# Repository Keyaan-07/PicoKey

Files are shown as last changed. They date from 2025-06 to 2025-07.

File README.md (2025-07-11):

# PicoKey 

I go to highschool, and teens are always around when i try to login to my mail or github or any other account, so my password can be compromised.  

To solve this, I created PicoKey, which is a hardware pass key in a very small form factor(34.5mm x 18.5mm). It uses the RP2350A chip, although I wanted to use my favourite MCU, the rp2040, it was not safe as a pass key, so I used the rp2350A this time, which is much more safer and secure than the RP2350A.  

I think it can also function as a USB-HID device because it has an external button too and 16Mb of memory size.

It has USB-A in the PCB itself soo need for external connectors, however, you either need to order a 2.0mm thick PCB(expensive) or you need to order a 1.6mm PCB(pretty cheap) and make up for the 0.4mm using tape or some other method.  

### Features:
> Small form factor: 3.45cm x 1.85 cm  
> Uses the latest MCU from Raspberyy Pi, the RP2350A  
> Could Potentially have HID Compatibility  
> USB inbuilt the PCB

Idea taken from ```@Rudy``` 's [RP2350 hardware key](https://github.com/Outdatedcandy92/PicoDucky)  

# How to Assemble this PCB?

It is basically a single pcb, so assembling this project means soldering on all the components.  

To solder, I would recommend buying a stencil along with the PCBs, or opting for PCBA from your PCB manufacturer, I am using [JLC](https://jlcpcb.com) for this, and I will be opting for PCBA, as this is a 2 sided board, it will be much easier for 1 side to be PCBA(bottom side) and other by hand(top side).  

The RP2350A is housed on the bottom side along with most of the components, and I have placed easy to solder components on the top, and the small pads for resistors and LED are a little bigger, which would help in soldering by hand.

# Why i chose to make this project
I chose to make this project mainly for 2 reasons:  

1. i wanted to have a secure hardware key and didn't wanna sign in using passwords in front of everyone.  

2. I wanted to try out making a 2 sided PCB(where components are on 2 sides), to learn how to make such projects and the learning curve for dual sided PCBs.  

# Images
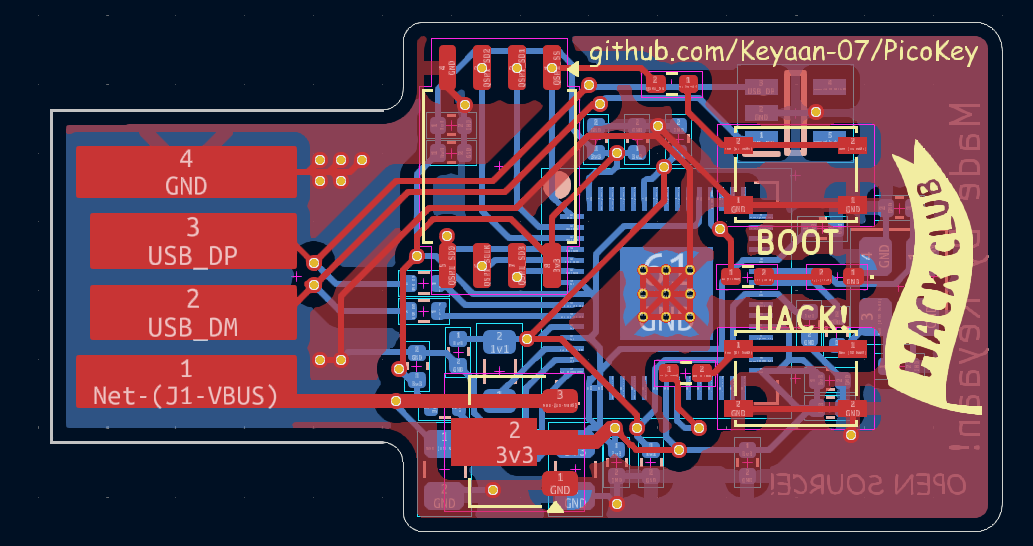
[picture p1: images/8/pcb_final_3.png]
final pcb img
  
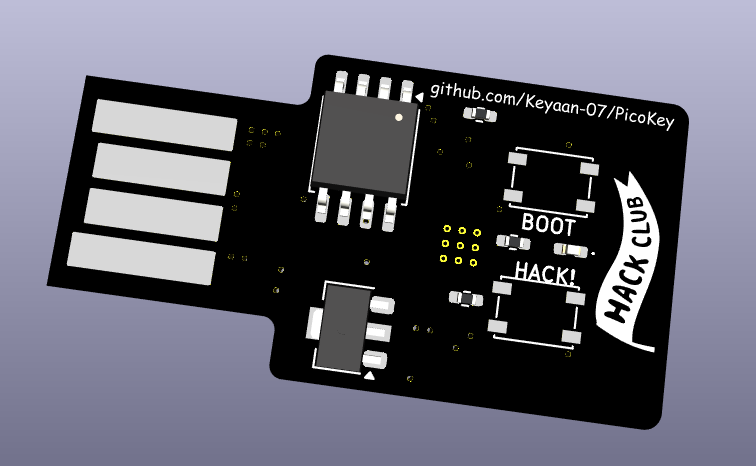
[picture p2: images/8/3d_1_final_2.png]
final cad 1
  
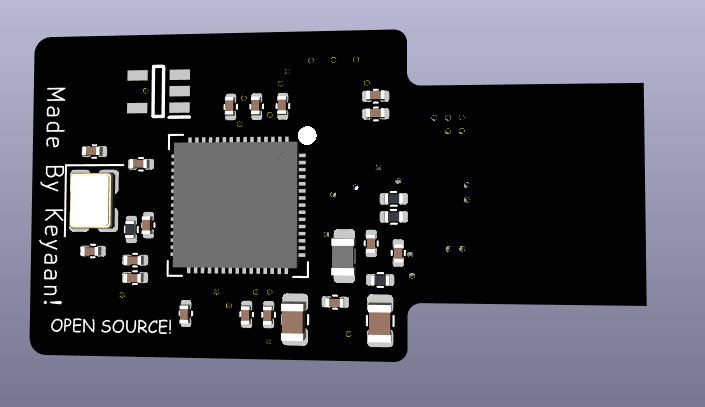
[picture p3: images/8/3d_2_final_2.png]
final cad 2
  
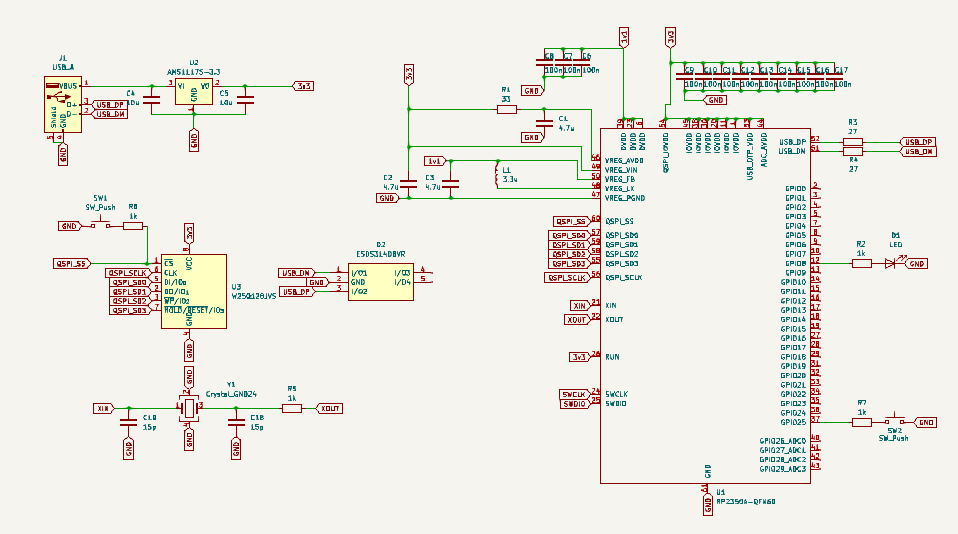
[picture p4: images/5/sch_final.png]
final sch img
  

# BOM

| ITEM NAME | ITEM PRICE | FUNCTION | URL |
| --- | --- | --- | --- |
| Pcb Manufacturing + stencil | 23.82 | main pcb and smt stencil | [https://jlcpcb.com](https://jlcpcb.com/) |
| PCB Components | 21.1131 | components on the PCB | [https://lcsc.com](https://lcsc.com/) |
|  Total | 44.93 | USD | |

# PCB Components Breakdown

### Note: There are a few resistors and capacitors, which had very high minimum order quantity(MOQ), about 50 pieces so i had to forcefully include those, which i will be utilising in my next highway projects. And tbh the prices were very less(about $0.02 per piece) so i think it is alright

### if DNO is yes, i am not ordering the respective parts and thus i have not included the cost in BOM.

| Id | Designator | Designation | MPN | Footprint | DNO - Do not order | MOQ | Price  | Quantity | Amount | Supplier link |
| -- | --- | --- | --- | --- | --- | --- | --- | --- | --- | --- |
| 1  | C1, C2, C3 | 4.7u | GRM155R61C475KE15D | 402 | No | Yes | 0.057  | 10 | 0.57 | https://lcsc.com/product-detail/Multilayer-Ceramic-Capacitors-MLCC-SMD-SMT_Murata-Electronics-GRM155R61C475KE15D_C426094.html |
| 2  | C10, C11, C12, C13, C14, C15, C16, C17, C6, C7, C8, C9 | 100n | GRM155R61H104JE14D | 402 | Yes | \-  | 0 | 36 | 0 | https://lcsc.com/product-detail/Multilayer-Ceramic-Capacitors-MLCC-SMD-SMT_Murata-Electronics-GRM155R61H104JE14D_C426067.html |
| 3  | C18, C19 | 15p | GJM1555C1H150FB01D | 402 | Yes | \-  | 0 | 6 | 0 | https://lcsc.com/product-detail/Multilayer-Ceramic-Capacitors-MLCC-SMD-SMT_Murata-Electronics-GJM1555C1H150FB01D_C441742.html |
| 4  | C4, C5 | 10u | CL21A106KBVNNNE | 805 | No | Yes | 0.046  | 5 | 0.23 | https://lcsc.com/product-detail/Multilayer-Ceramic-Capacitors-MLCC-SMD-SMT_Samsung-Electro-Mechanics-CL21A106KBYQNNE_C2932476.html |
| 5  | D1 | LED | 19-213-GHC-YR1S1N-3T  | 402 | Yes | \-  | 0 | 3 | 0 | https://www.lcsc.com/product-detail/LED-Indication-Discrete_Everlight-Elec-16-213-GHC-YR1S1N-3T_C2980183.html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 |
| 6  | D2 | ESDS314DBVR | ESD5314DBVR | 402 | No | Yes | 0.212  | 5 | 1.06 | https://lcsc.com/product-detail/ESD-and-Surge-Protection-TVS-ESD_TI-ESDS314DBVR_C1847859.html |
| 7  | J1 | USB_A | \- | USBPCB | On PCB | \-  | \- | \- | \- | \- |
| 8  | L1 | 3.3u | A201610S3R3-101-T | 806 | No | Yes | 0.2592 | 5 | 1.3 | https://lcsc.com/product-detail/Power-Inductors_Abracon-LLC-AOTA-B201610S3R3-101-T_C42411119.html |
| 9  | R1 | 33 | RT0402BRD0733RL | 402 | No | Yes | 0.0198 | 50 | 0.99 | https://lcsc.com/product-detail/Chip-Resistor-Surface-Mount_YAGEO-RT0402BRD0733RL_C852729.html |
| 10 | R2, R5, R6, R7 | 1k | CRCW040210K0FKEDHP | 402 | No | Yes | 0.023  | 20 | 0.46 | https://lcsc.com/product-detail/Chip-Resistor-Surface-Mount_Vishay-Intertech-CRCW04021K00FKEDHP_C313354.html |
| 11 | R3, R4 | 27 | ERJ2GEJ270X | 402 | Yes | \-  | 0 | 6 | 0 | https://lcsc.com/product-detail/Chip-Resistor-Surface-Mount_PANASONIC-ERJ2GEJ270X_C278580.html |
| 12 | SW1, SW2 | SW_Push | K-PTS810SJMS205MTLFSG | SW_SPST_PTS810 | No | No  | 0.6 | 6 | 3.6 | https://lcsc.com/product-detail/Tactile-Switches_C-K-PTS810SJM250SMTRLFS_C116501.html |
| 13 | U1 | RP2350A-QFN60 | RPi2350 | QFN-60 | No | No  | 1.514  | 3 | 4.542  | https://www.silverlineelectronics.in/collections/the-raspberry-pi/products/rp2350a-raspberry-pi-microcontroller-chip-in-stock-silverline-india |
| 14 | U2 | AMS1117S-3.3  | AMS1117-3.3 | SOT-89-3 | No | Yes | 0.1 | 5 | 0.5 | https://lcsc.com/product-detail/Voltage-Regulators-Linear-Low-Drop-Out-LDO-Regulators_JSMSEMI-AMS1117S-3-3_C917152.html |
| 15 | U3 | W25Q128JVS | W25Q128JVSIM | SOIC-8_5.3x5.3mm_P1.27mm | Yes | \-  | 0 | 3 | 0 | https://lcsc.com/product-detail/NOR-FLASH_Winbond-Elec-W25Q128JVSIM_C2613930.html |
| 16 | Y1 | Crystal_GND24 | ABM8-27-T3 | Crystal_SMD_3225-4Pin_3.2x2.5mm | No | No  | 0.3737 | 3 | 1.1211 | https://www.lcsc.com/product-detail/Crystals_Abracon-LLC-ABM8-272-T3_C20625731.html?s_z=n_abm8 |
| | | Shipping | 3.74 | | | | | | | |
| | | Handling fee  | 3 | | | | | | | |
| | | Total | 21.1131 | USD | | | | | | |

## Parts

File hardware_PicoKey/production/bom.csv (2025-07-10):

Designator | Footprint | Quantity | Value | LCSC Part #
C1, C2, C3 | 402 | 3 | 4.7u
C10, C11, C12, C13, C14, C15, C16, C17, C6, C7, C8, C9 | 402 | 12 | 100n
C18, C19 | 402 | 2 | 15p
C4, C5 | 805 | 2 | 10u
D1 | 402 | 1 | LED
D2 | ESDS314BVR_SOT95P280X145-5N | 1 | ESDS314DBVR
J1 | USBPCB | 1 | USB_A
L1 | 805 | 1 | 3.3u
R1 | 402 | 1 | 33
R2, R5, R6, R7 | 402 | 4 | 1k
R3, R4 | 402 | 2 | 27
SW1, SW2 | SW_SPST_PTS810 | 2 | SW_Push
U1 | RP2350A_QFN-60_EP_7.75x7.75_Pitch0.4mm | 1 | RP2350A-QFN60
U2 | SOT-89-3 | 1 | AMS1117S-3.3
U3 | SOIC-8_5.3x5.3mm_P1.27mm | 1 | W25Q128JVS
Y1 | Crystal_SMD_3225-4Pin_3.2x2.5mm | 1 | Crystal_GND24

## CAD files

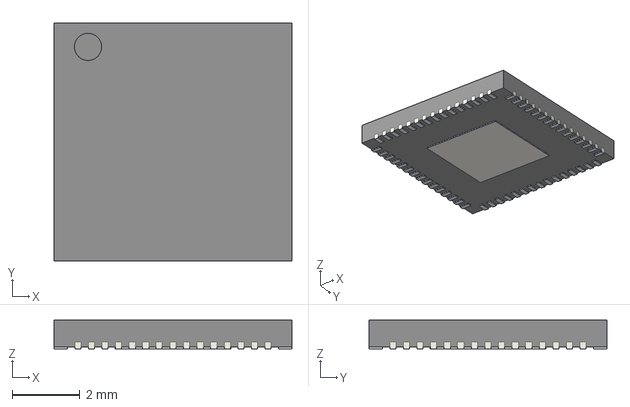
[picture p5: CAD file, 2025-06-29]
hardware_PicoKey/footprints/RP2350A-QFN60.step
7.00 x 7.00 x 0.85 mm

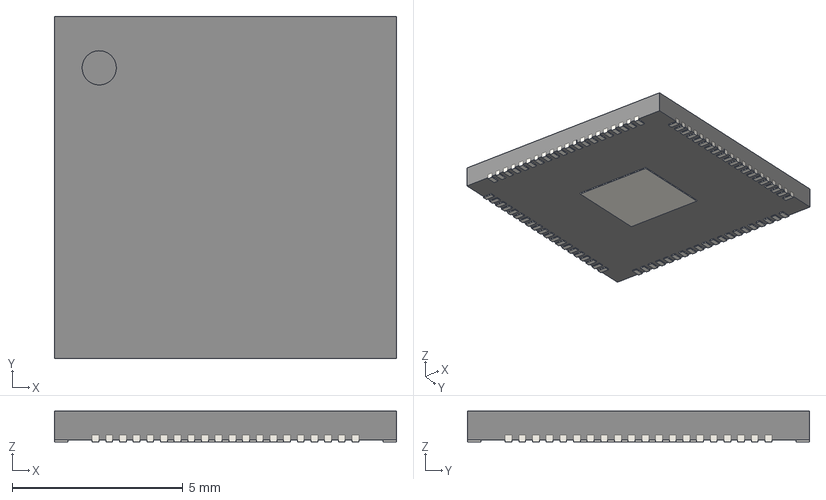
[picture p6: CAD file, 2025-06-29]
hardware_PicoKey/footprints/RP2350B-QFN80.step
10.0 x 10.0 x 0.9 mm

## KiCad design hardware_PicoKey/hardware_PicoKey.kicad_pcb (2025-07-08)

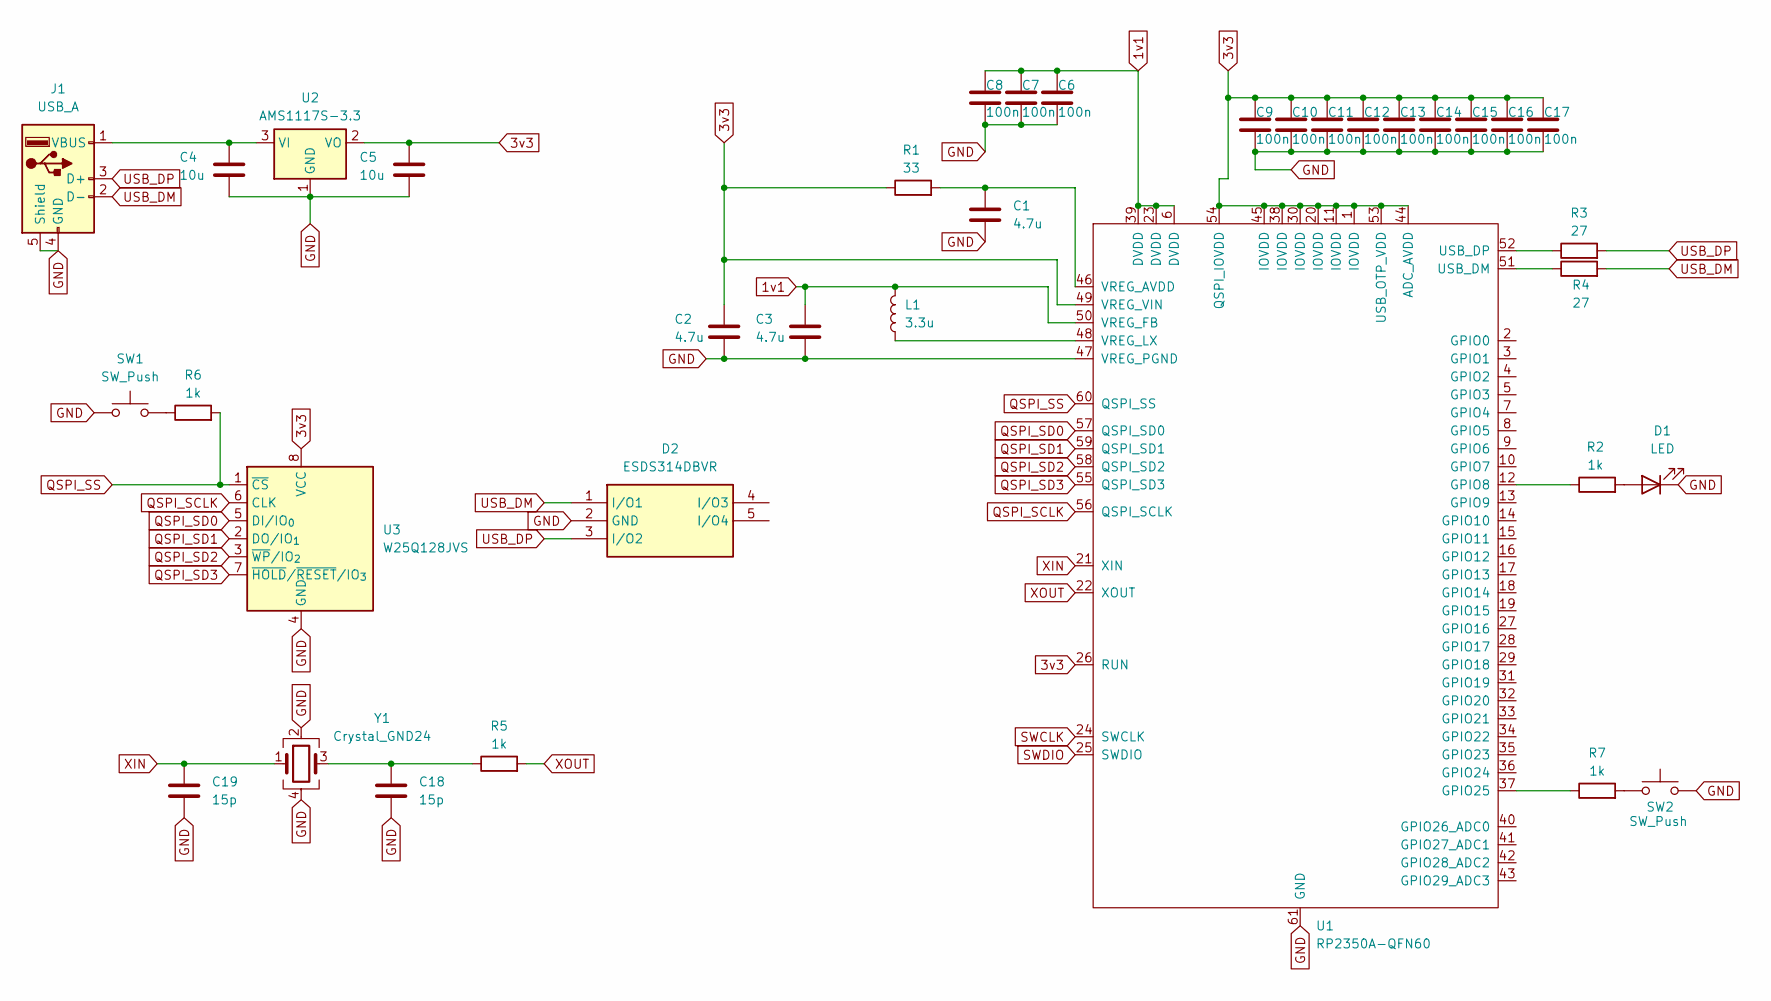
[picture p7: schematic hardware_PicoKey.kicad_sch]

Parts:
C1, C2, C3: 4.7u; C_0402_1005Metric
C4, C5: 10u; C_0805_2012Metric
C6, C7, C8, C9, C10, C11, C12, C13, C14, C15, C16, C17: 100n; C_0402_1005Metric
C18, C19: 15p; C_0402_1005Metric
D1: LED; LED_0402_1005Metric_Pad0.77x0.64mm_HandSolder
D2: ESDS314DBVR; ESDS314BVR_SOT95P280X145-5N; Mouser Part Number 595-ESDS314DBVR
J1: USB_A; USBPCB
L1: 3.3u; L_0805_2012Metric
R1: 33; R_0402_1005Metric
R2, R6, R7: 1k; R_0402_1005Metric_Pad0.72x0.64mm_HandSolder
R3, R4: 27; R_0402_1005Metric
R5: 1k; R_0402_1005Metric
SW1, SW2: SW_Push; SW_SPST_PTS810
U1: RP2350A-QFN60; RP2350A_QFN-60_EP_7.75x7.75_Pitch0.4mm
U2: AMS1117S-3.3; SOT-89-3
U3: W25Q128JVS; SOIC-8_5.3x5.3mm_P1.27mm
Y1: Crystal_GND24; Crystal_SMD_3225-4Pin_3.2x2.5mm

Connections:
1v1: C3.1, C6.1, C7.1, C8.1, L1.2, U1.6 (DVDD), U1.23 (DVDD), U1.39 (DVDD), U1.50 (VREG_FB)
3v3: C2.1, C5.1, C9.1, C10.1, C11.1, C12.1, C13.1, C14.1, C15.1, C16.1, C17.1, R1.1, U1.1 (IOVDD), U1.11 (IOVDD), U1.20 (IOVDD), U1.26 (RUN), U1.30 (IOVDD), U1.38 (IOVDD), U1.44 (ADC_AVDD), U1.45 (IOVDD), U1.49 (VREG_VIN), U1.53 (USB_OTP_VDD), U1.54 (QSPI_IOVDD), U2.2 (VO), U3.8 (VCC)
GND: C1.2, C2.2, C3.2, C4.2, C5.2, C6.2, C7.2, C8.2, C9.2, C10.2, C11.2, C12.2, C13.2, C14.2, C15.2, C16.2, C17.2, C18.2, C19.2, D1.1 (K), D2.2 (GND), J1.4 (GND), J1.5 (Shield), SW1.1, SW2.2, U1.47 (VREG_PGND), U1.61 (GND), U2.1 (GND), U3.4 (GND), Y1.2, Y1.4
unnamed: C18.1, R5.1, Y1.3
unnamed: D1.2 (A), R2.2
unnamed: C4.1, J1.1 (VBUS), U2.3 (VI)
unnamed: R6.1, SW1.2
unnamed: R7.2, SW2.1
unnamed: R2.1, U1.12 (GPIO8)
unnamed: R7.1, U1.37 (GPIO25)
unnamed: R4.1, U1.51 (USB_DM)
unnamed: R3.1, U1.52 (USB_DP)
unnamed: C1.1, R1.2, U1.46 (VREG_AVDD)
unnamed: L1.1, U1.48 (VREG_LX)
QSPI_SCLK: U1.56 (QSPI_SCLK), U3.6 (CLK)
QSPI_SD0: U1.57 (QSPI_SD0), U3.5 (DI/IO_{0})
QSPI_SD1: U1.59 (QSPI_SD1), U3.2 (DO/IO_{1})
QSPI_SD2: U1.58 (QSPI_SD2), U3.3 (~WP/IO_{2})
QSPI_SD3: U1.55 (QSPI_SD3), U3.7 (~HOLD/~RESET/IO_{3})
QSPI_SS: R6.2, U1.60 (QSPI_SS), U3.1 (~CS)
SWCLK: U1.24 (SWCLK)
SWDIO: U1.25 (SWDIO)
USB_DM: D2.1 (I/O1), J1.2 (D-), R4.2
USB_DP: D2.3 (I/O2), J1.3 (D+), R3.2
XIN: C19.1, U1.21 (XIN), Y1.1
XOUT: R5.2, U1.22 (XOUT)

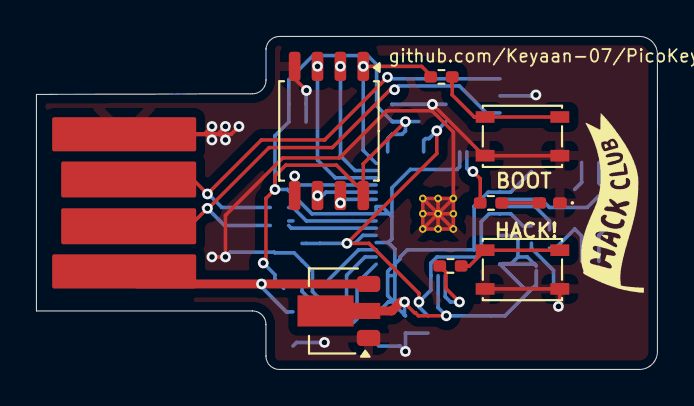
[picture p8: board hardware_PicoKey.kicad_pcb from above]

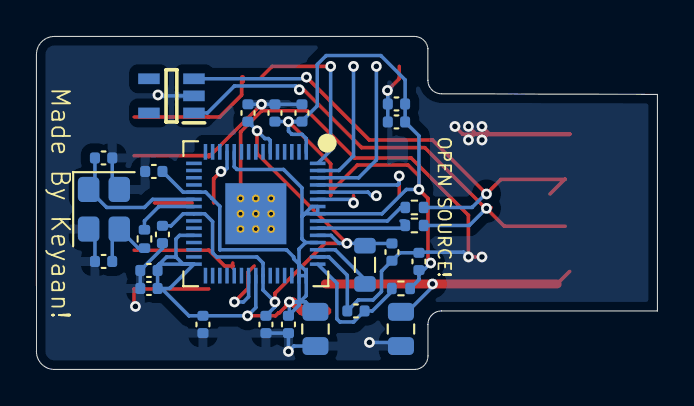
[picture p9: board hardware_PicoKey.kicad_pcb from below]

Board: 2 copper layers, 34.5 x 18.5 mm, 36 parts (27 on the bottom side), 24 nets.

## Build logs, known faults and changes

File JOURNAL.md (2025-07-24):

---
title: "PicoKey"
author: "Keyaan"
description: "A Pass Key(Like Yubikey) using the RP2350A from Raspberyy Pi!"
created_at: "2025-06-26"
---
# Total time spent: about 6 hours
# this work is not at all copied from rudy, i wanted to create my own thats all

----
# June 26 2025
Yup, I wanna make a hardware key. I was inspired by yubikey, [orpheus pico guide](http://orpheuspico.hackclub.com/docs/pico/guides/passkey), and the [RP2350 hardware key](https://github.com/Outdatedcandy92/PicoDucky) by ```@Rudy```

I might start from tomorrow.  

----
# June 27 2025

Beginning my work on PicoKey from today. The things i will try to accomplish:
> PCB Trace USB Connector  
> Use an RP2350 instead of RP2040 this time:(  
> smallest possible footprint  
> also add HID compatability
  
I wanted to use the RP2040 but it is apparently not secure enough so now i have to use the RP2350 :(

Gotta start with the schematic(i didn't)

----
# June 29 2025

Finally, my test is over today and now i can work on this PCB. so, starting with the schematic from now on.

### Time spent: about 1 hour (had to learn the rp2350 design guide)

----
# June 30 2025
I did the work yesterday but then i was ordered to chut down the laptop immediately, so i had to go, anyways, here are the pictures from yesterday:

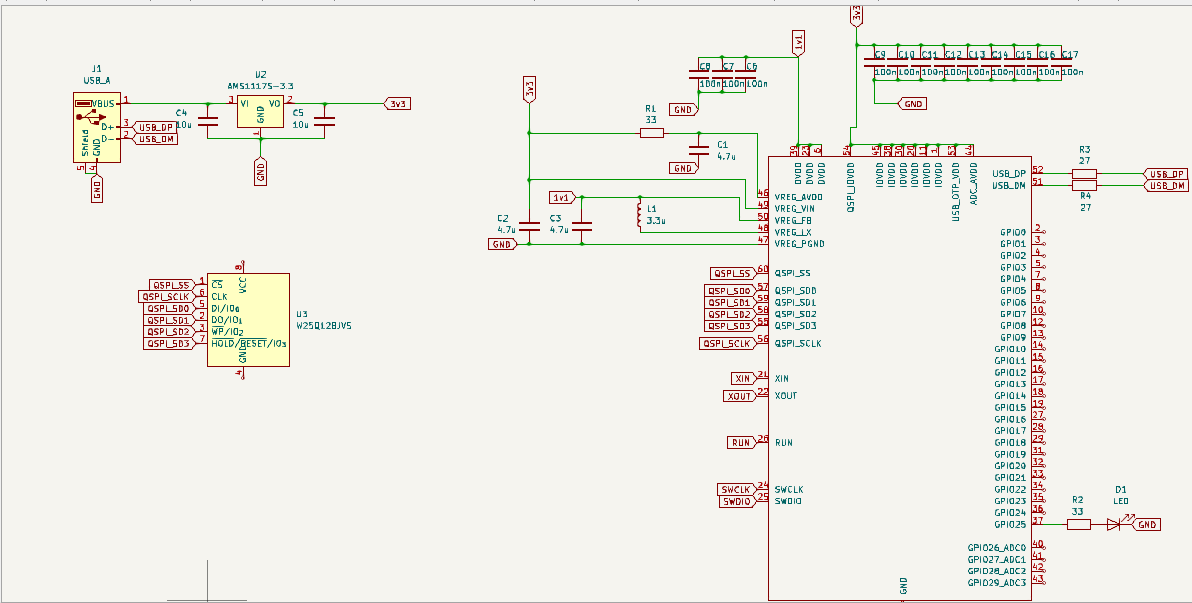
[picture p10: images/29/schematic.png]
schematic


i didn't work on anything else.

----
# July 1 2025

I have thought of something, maybe, i can also make the device as an HID, like how ```@Rudy``` made it, so i am gonna do that probably and complete the pcb today itself.  
I think the schematic is complete, here it is:  
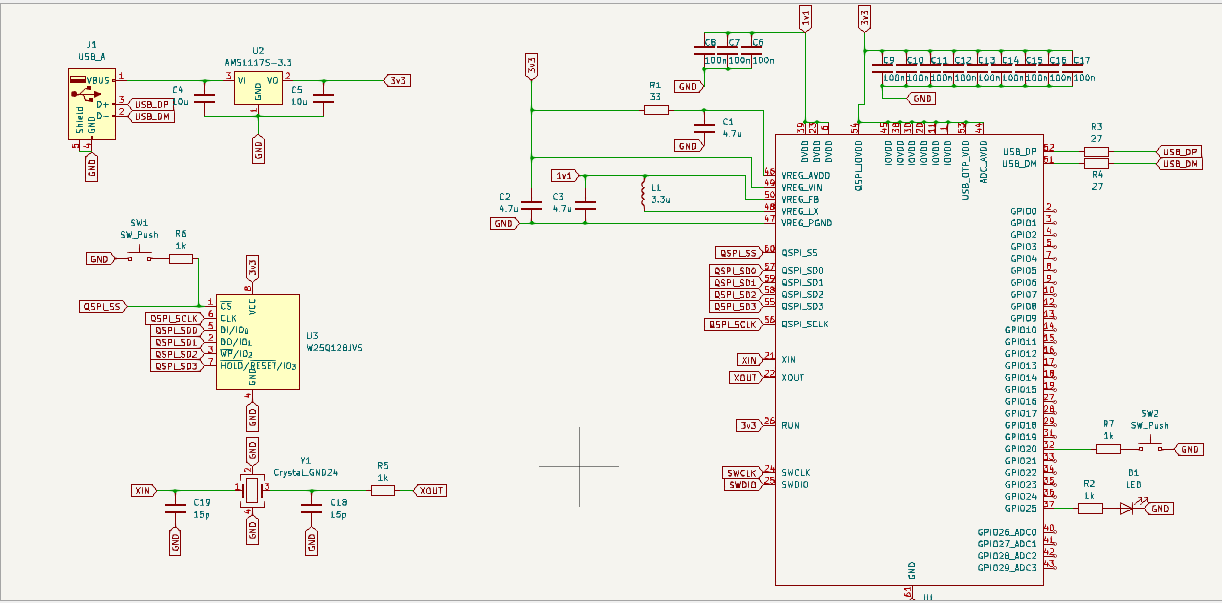
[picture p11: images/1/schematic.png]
schematic july 1


other than the schematic, i worked on the pcb, here is the current progress:  
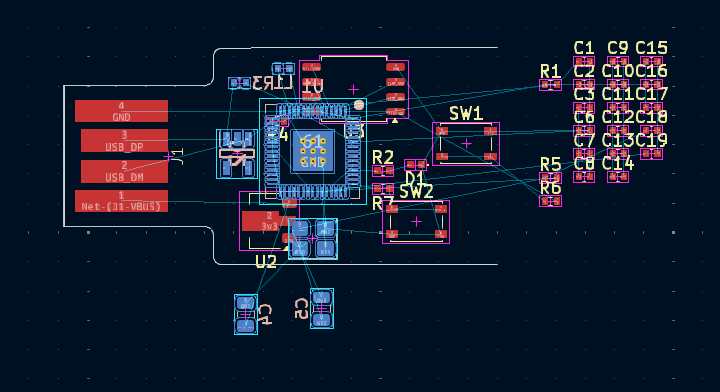
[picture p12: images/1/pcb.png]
  

I also added an ESD protection IC, here it is:  
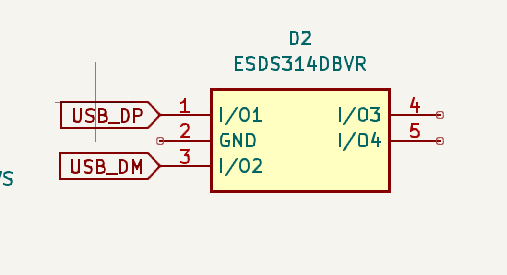
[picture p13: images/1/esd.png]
esd IC
  

I worked more on the PCB, yeah, i realised that making a dual sided PCB is HARD, i alwasys that that i could do it easily, but no, it is hard :/
Anyways, here is the updated PCB:  
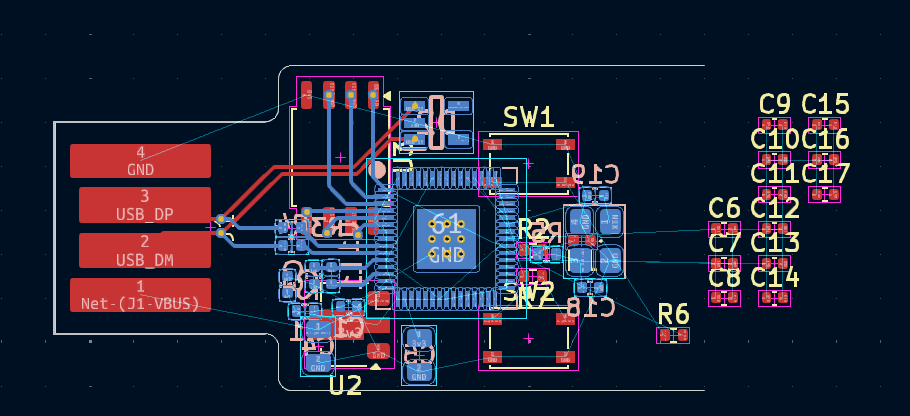
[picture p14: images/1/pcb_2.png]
  

### TIme Spent Today: about 1 hour and 45 mins

# July 2 2025
Yooo i am in school, gotta work on the pcb a lil bit.  
Here it the work i did:  
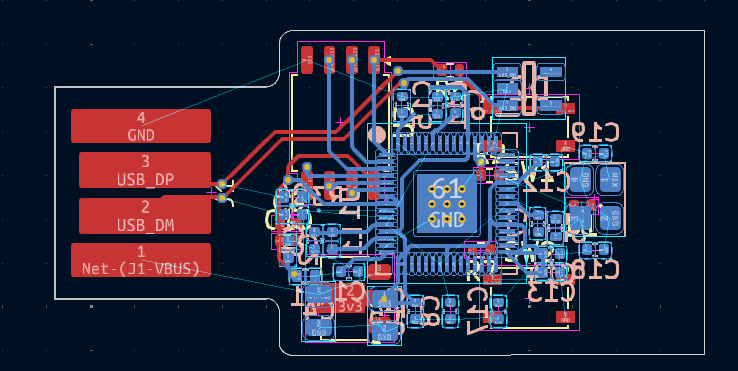
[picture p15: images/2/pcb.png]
  

i might just complete the PCB today if i get time. 
This two sided PCB is so hard to deal with 😭

### Time Spent Today: about 45 mins

# July 4 2025

I am in school againn!!! Gotta work on the PCB.
in school, i just changed the PCB side and make it round rectangular. nothing more nothing fancy, although i attracted attention of a few of my friends when doing so!

Now i am starting to work again. will update soon

yay, i worked and i think the PCB is complete. the one thing that amazes pcb makers:

  

And Now the PCB:  
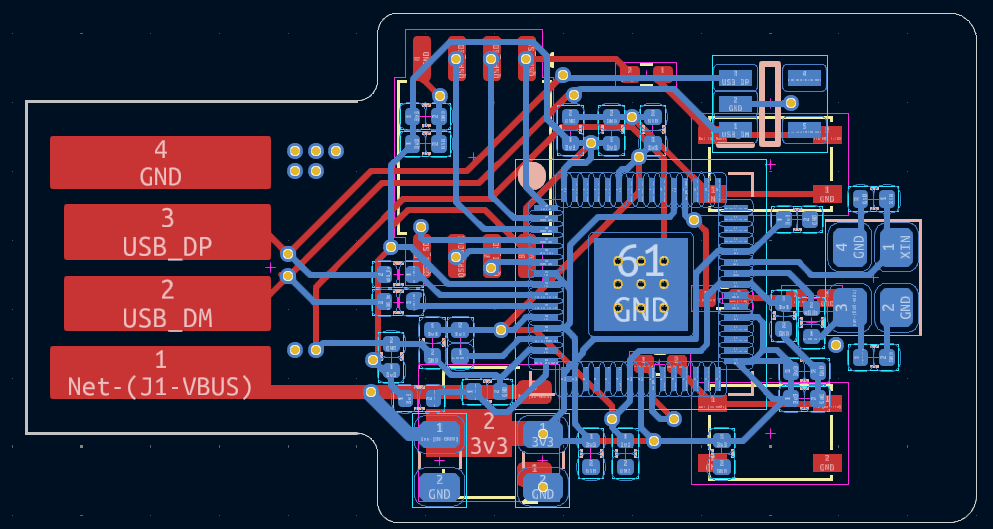
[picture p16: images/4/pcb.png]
  
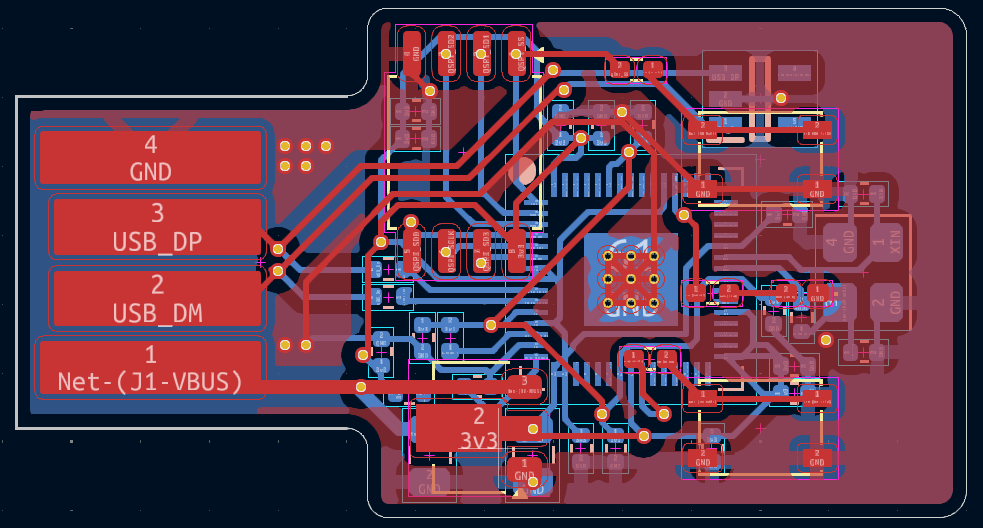
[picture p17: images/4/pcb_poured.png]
  

I still have to add some silkscreens and will do that later or tomorrow

### Time Spent Today: 1 hour 10 mins

# July 5 2025
worked on the pcb, added silkscreen layers and stuff, the final size comes to 34.5mm x 18.5mm, nice. Here is the final image of the pcb and the schematic and the 3d model:  
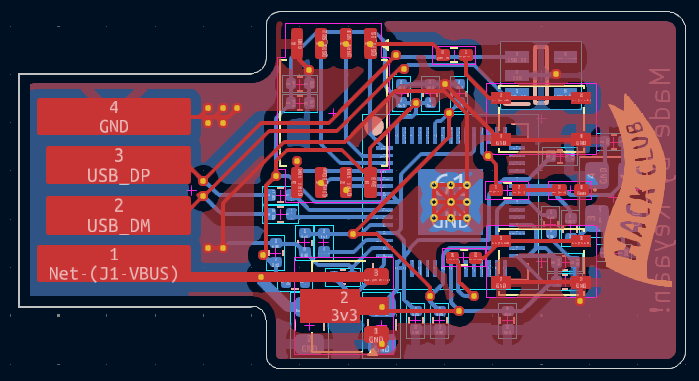
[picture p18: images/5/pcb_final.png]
final pcb img

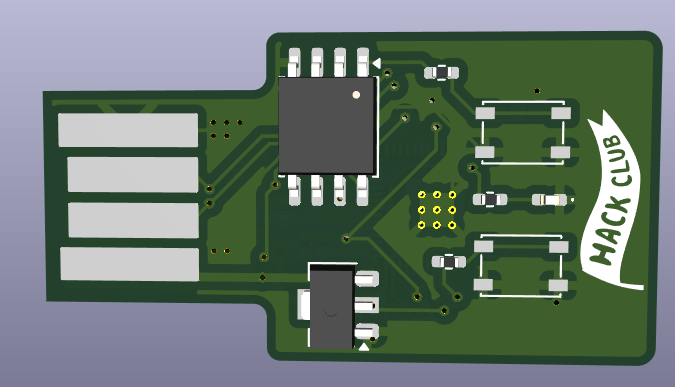
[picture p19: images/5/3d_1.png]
3d 1

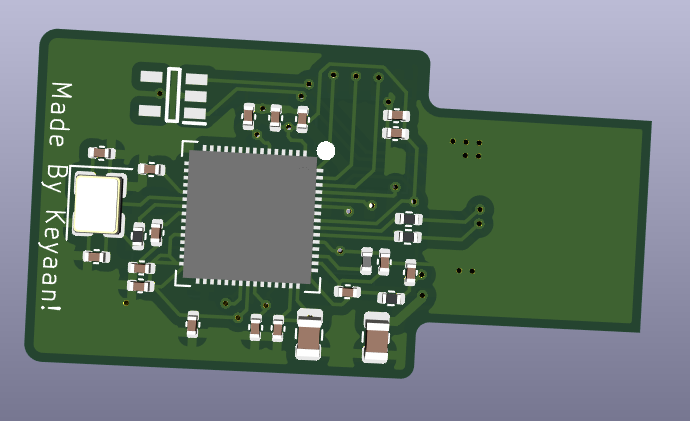
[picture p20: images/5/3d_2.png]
3d 2

final sch img

# July 7 2025:  
I will have to change the footprint of the 3.3uH inductor used for the RP2350A inbuilt regulator. Gonna do that rn.

I am done, here are the updated images:  
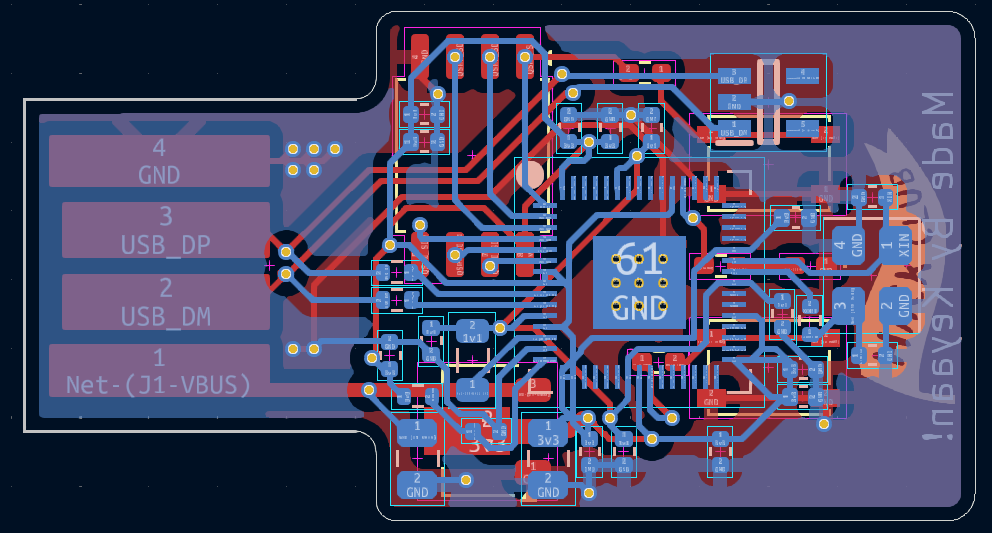
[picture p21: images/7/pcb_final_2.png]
final pcb img

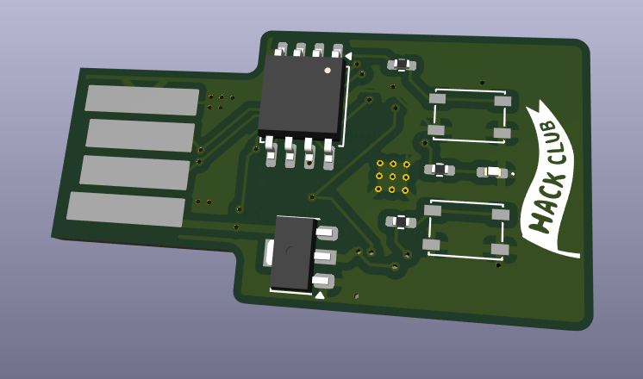
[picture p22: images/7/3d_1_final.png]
final cad 1

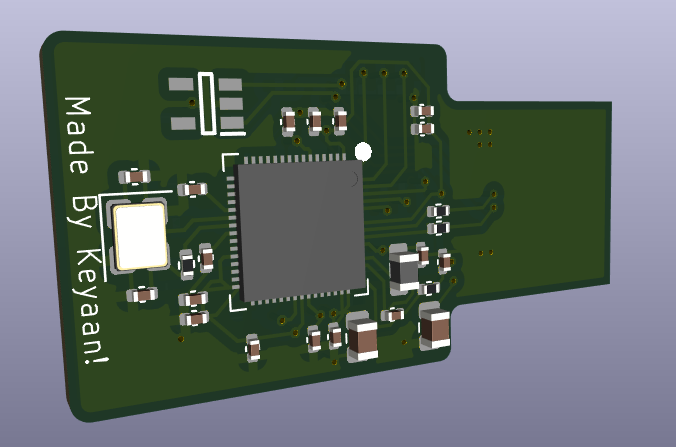
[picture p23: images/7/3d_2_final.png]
final cad 2

final sch img

Now i am gonna try to finish writing the README tonight itself.

Oh hell nah, i forgot to label BOOTSEL AND THE BUTTON, gonna do that just now

### Time Spent Today: 10 mins

# July 8 2025
I updated the silkscreen a little bit now this is how it looks:  

final pcb img  
final cad 1  
final cad 2  
final sch img  

Now i am gonna start writing the BOM and write more README and 

And i did very little stuff.
### Time Spent Today: 10 mins

# July 9 2025
Uhhhh i dont wanna procastinate but i wanna complete and submit asap, i still have to write the BOM for it fkjhadfjkshakjdsfhkj.    

oh wait, i just realised that if i order from JLC, the declared value will be 12 USD, which is too much which i can't pay, so i will have to switch to ordering the pcb and stencil from JLC and components form LCSC.

# July 11 2025:
worked a bit on the BOm today, made it completely and now gonna work on making all the other things for submission

### Time Spent Today: 45 mins 

# July 24 2025
RP2350A has arrived!!!! 
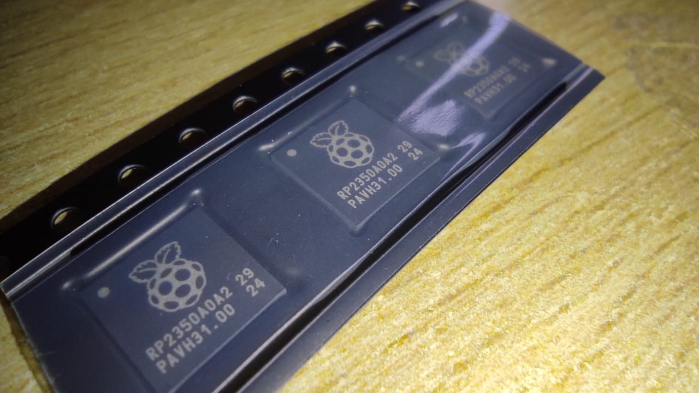
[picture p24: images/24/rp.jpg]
rp2350a arrived!!


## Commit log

2025-06-29 started with schematic
    [hardware_PicoKey.kicad_pcb, hardware_PicoKey.kicad_sch]
2025-06-29 add footprints for rp2350A and rp2350B
    [RP2350A-QFN60.step, RP2350B-QFN80.step]
2025-07-01 schematic doneee
2025-07-01 sch + pcb
    [hardware_PicoKey.kicad_pcb, hardware_PicoKey.kicad_sch]
2025-07-04 pcb and journaling
    [hardware_PicoKey.kicad_pcb]
2025-07-05 pcb donee
    [bom.csv, designators.csv, hardware_PicoKey.kicad_pcb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]
2025-07-10 pcb and BOM
    [BOM.xlsx, bom.csv, pcb_components.xlsx]
2025-07-11 pcb compoents added
    [pcb_components.csv, pcb_components.xlsx]
2025-07-11 BOM Update
    [BOM.csv, BOM.xlsx]
